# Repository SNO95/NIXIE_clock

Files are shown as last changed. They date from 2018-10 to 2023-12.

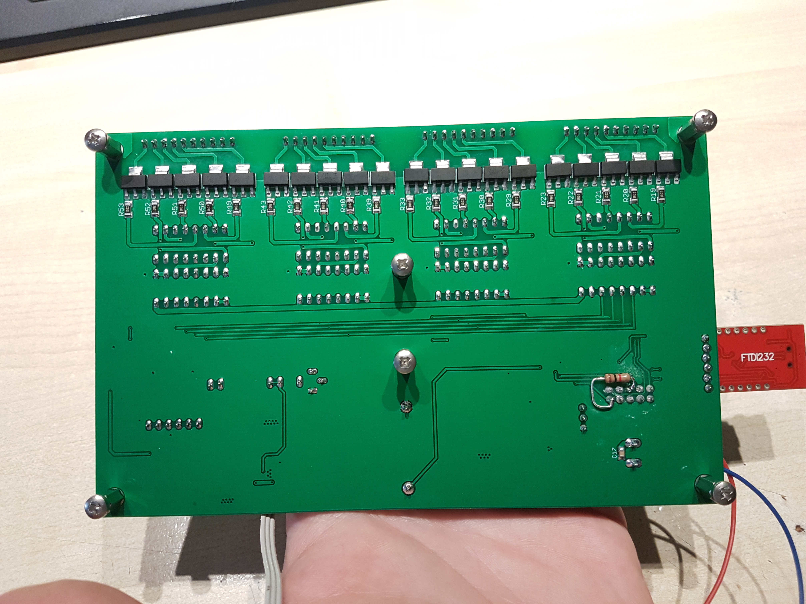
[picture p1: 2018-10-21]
20181021_120455.jpg

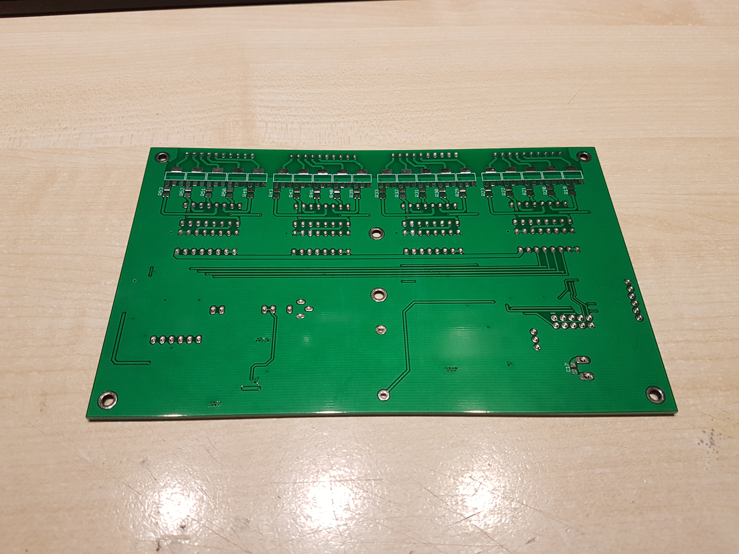
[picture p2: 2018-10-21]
20181021_120423.jpg

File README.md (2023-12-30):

# NIXIE_clock
ATmega328p and DS3231 based nixie clock.
PCBs are from JLC PCB, the first version had some errors (pictures are the first version, the battery hodlers silk screen was off by 0.5mm and the p channel mosfets in the h bridge were wired wrong, and I forgot the reset pullup on the ATmega) but I think they are fixed now. If you find anything please let me know.



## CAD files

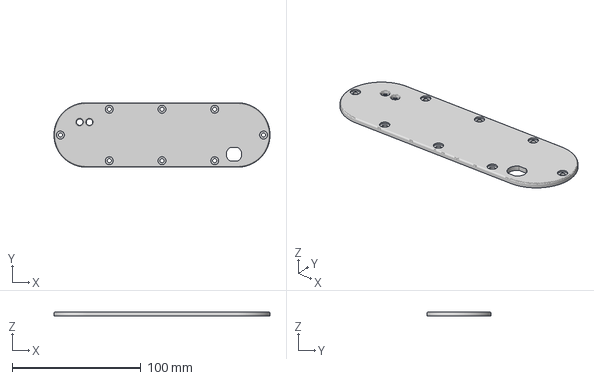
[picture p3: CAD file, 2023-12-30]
backplate.3mf
168.0 x 50.0 x 3.00 mm

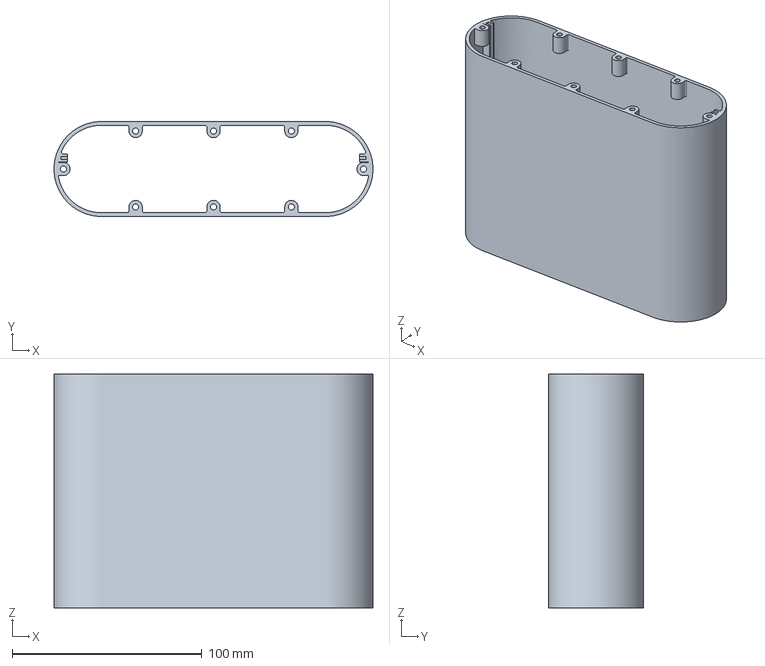
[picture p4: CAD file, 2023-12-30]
nixie body.3mf
168.0 x 50.0 x 123.0 mm

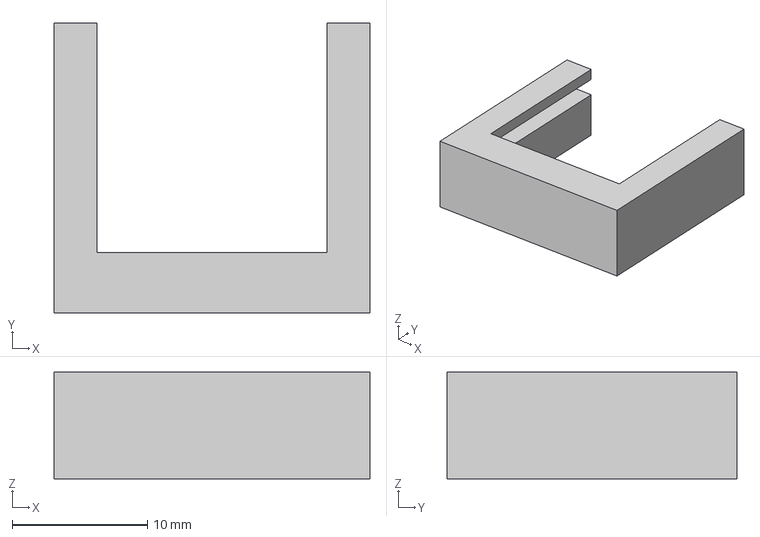
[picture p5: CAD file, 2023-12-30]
switch bracket.3mf
23.4 x 21.5 x 7.90 mm

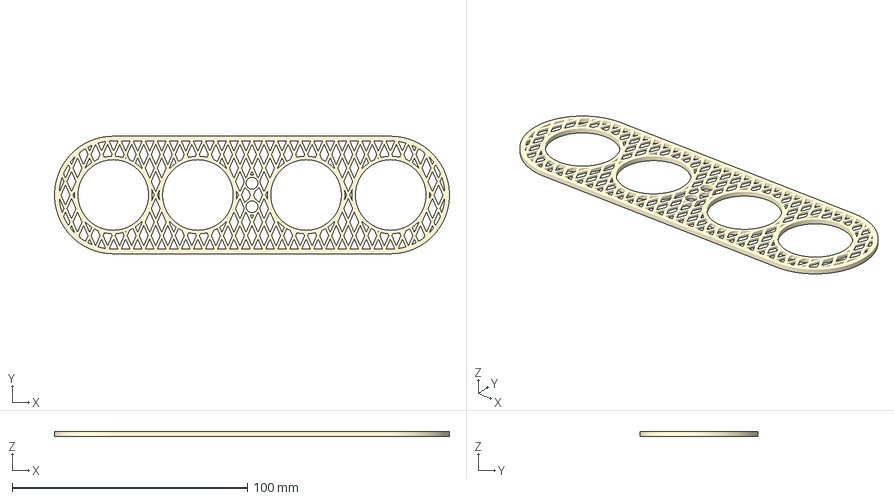
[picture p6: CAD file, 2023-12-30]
nixie grille.3mf
168.0 x 50.0 x 2.00 mm

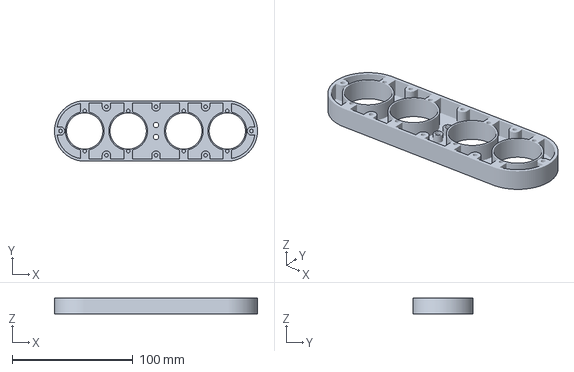
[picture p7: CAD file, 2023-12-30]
nixie panel.3mf
168.0 x 50.0 x 13.0 mm

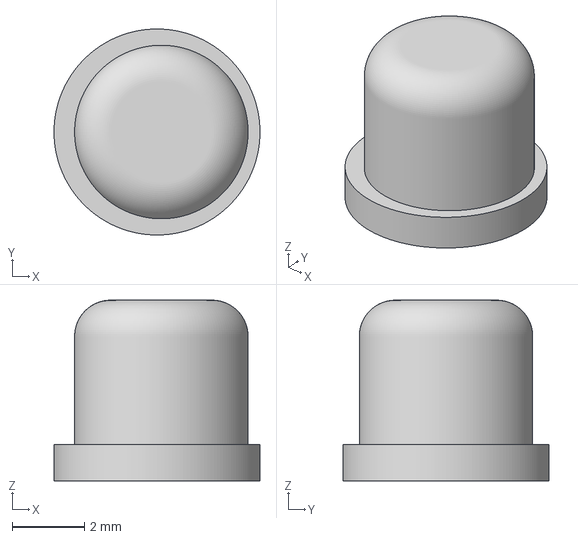
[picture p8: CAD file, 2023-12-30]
Button.3mf
5.70 x 5.70 x 5.00 mm

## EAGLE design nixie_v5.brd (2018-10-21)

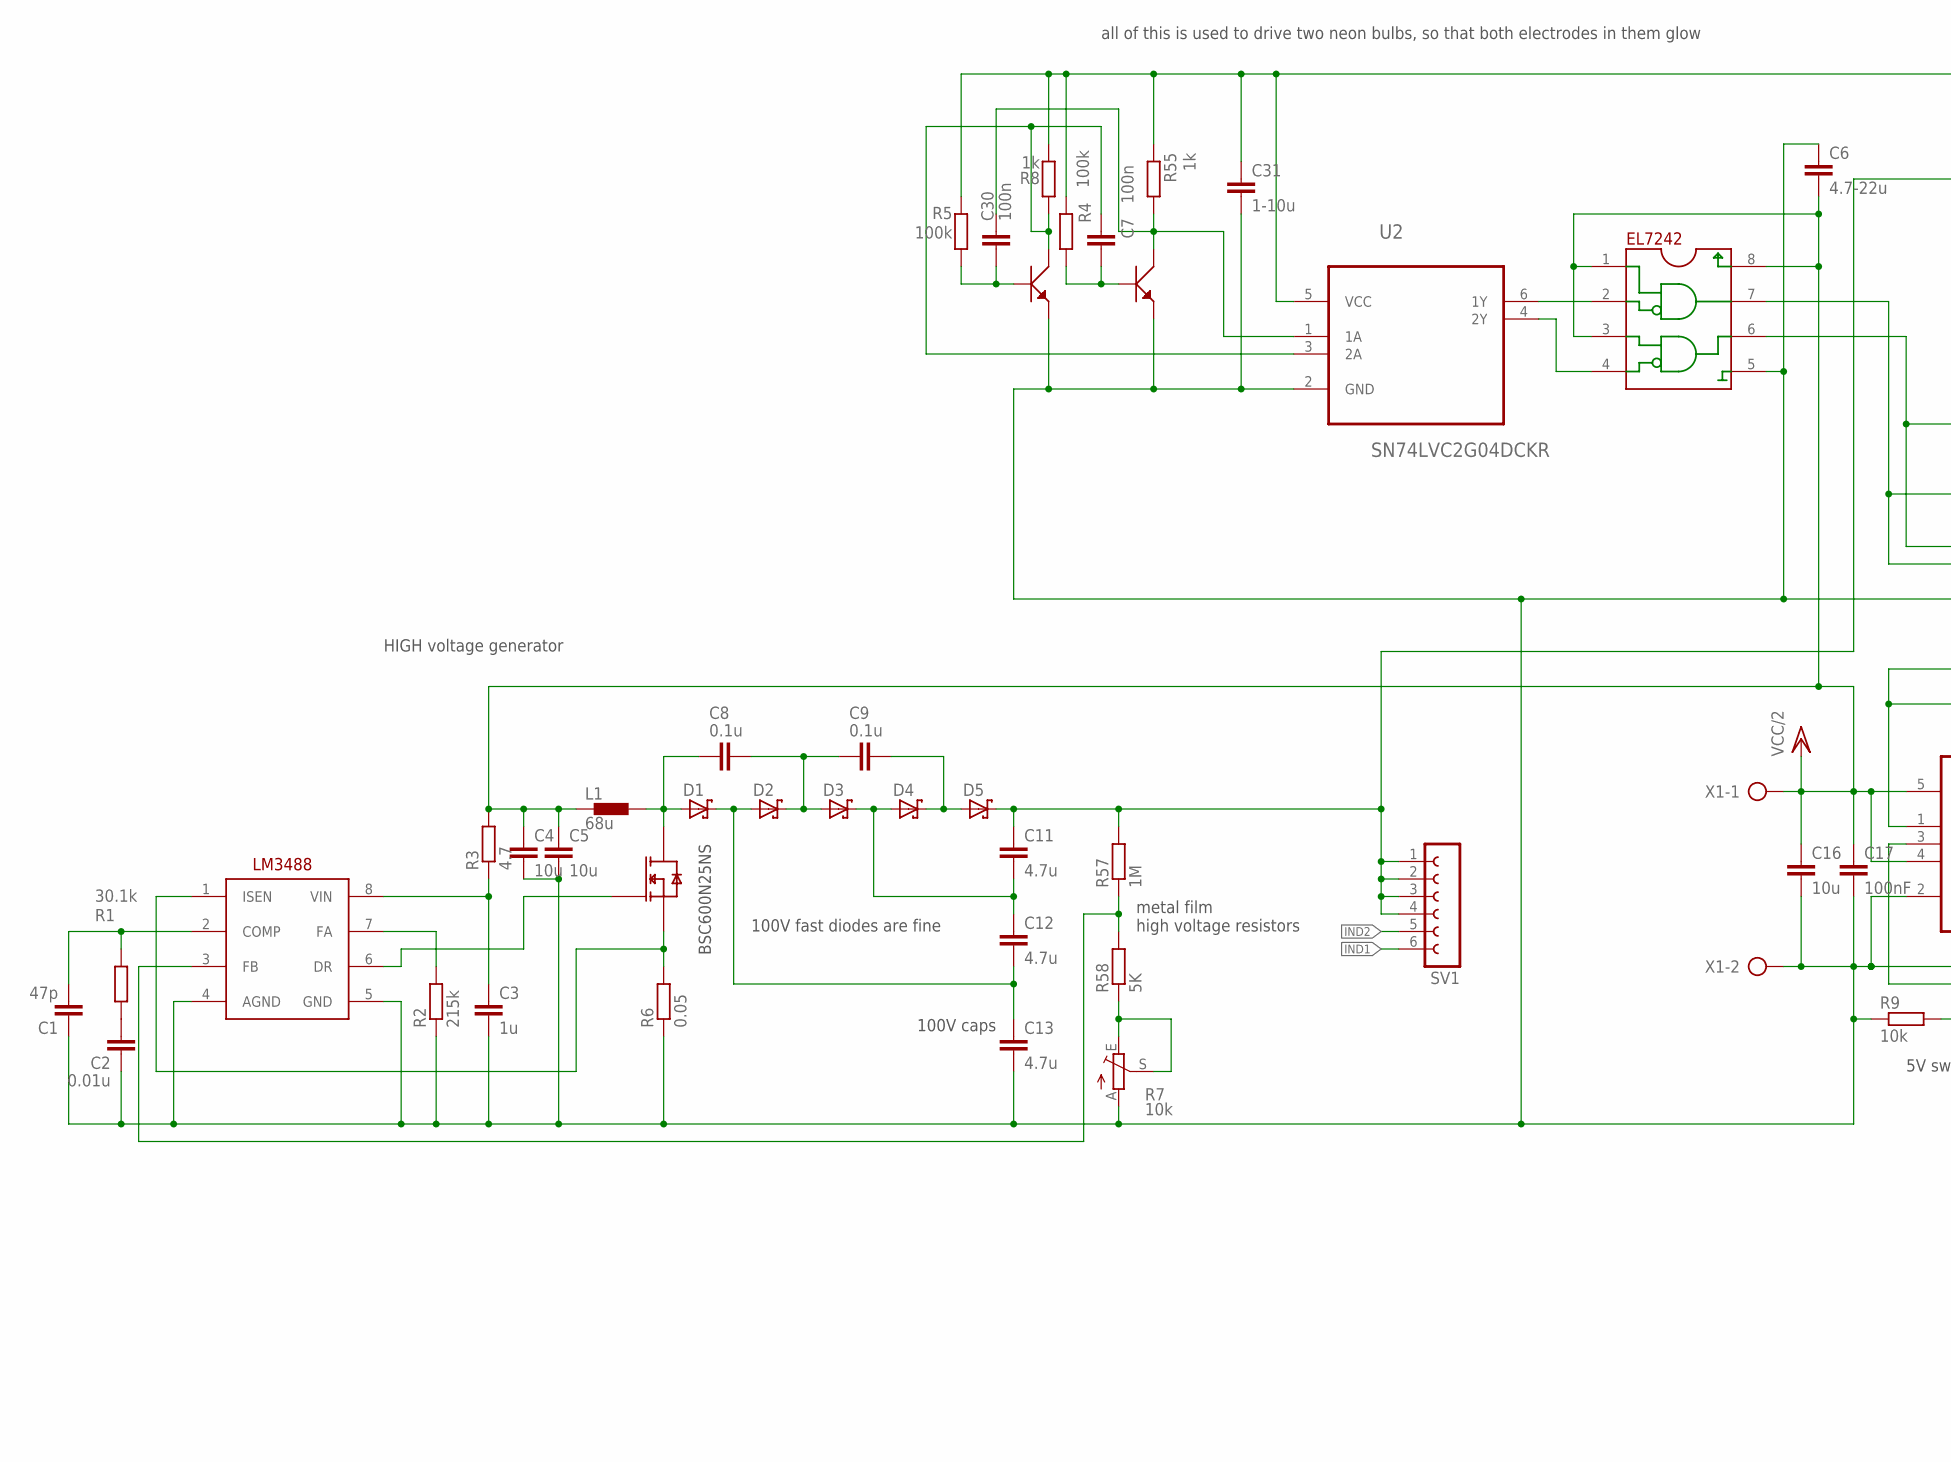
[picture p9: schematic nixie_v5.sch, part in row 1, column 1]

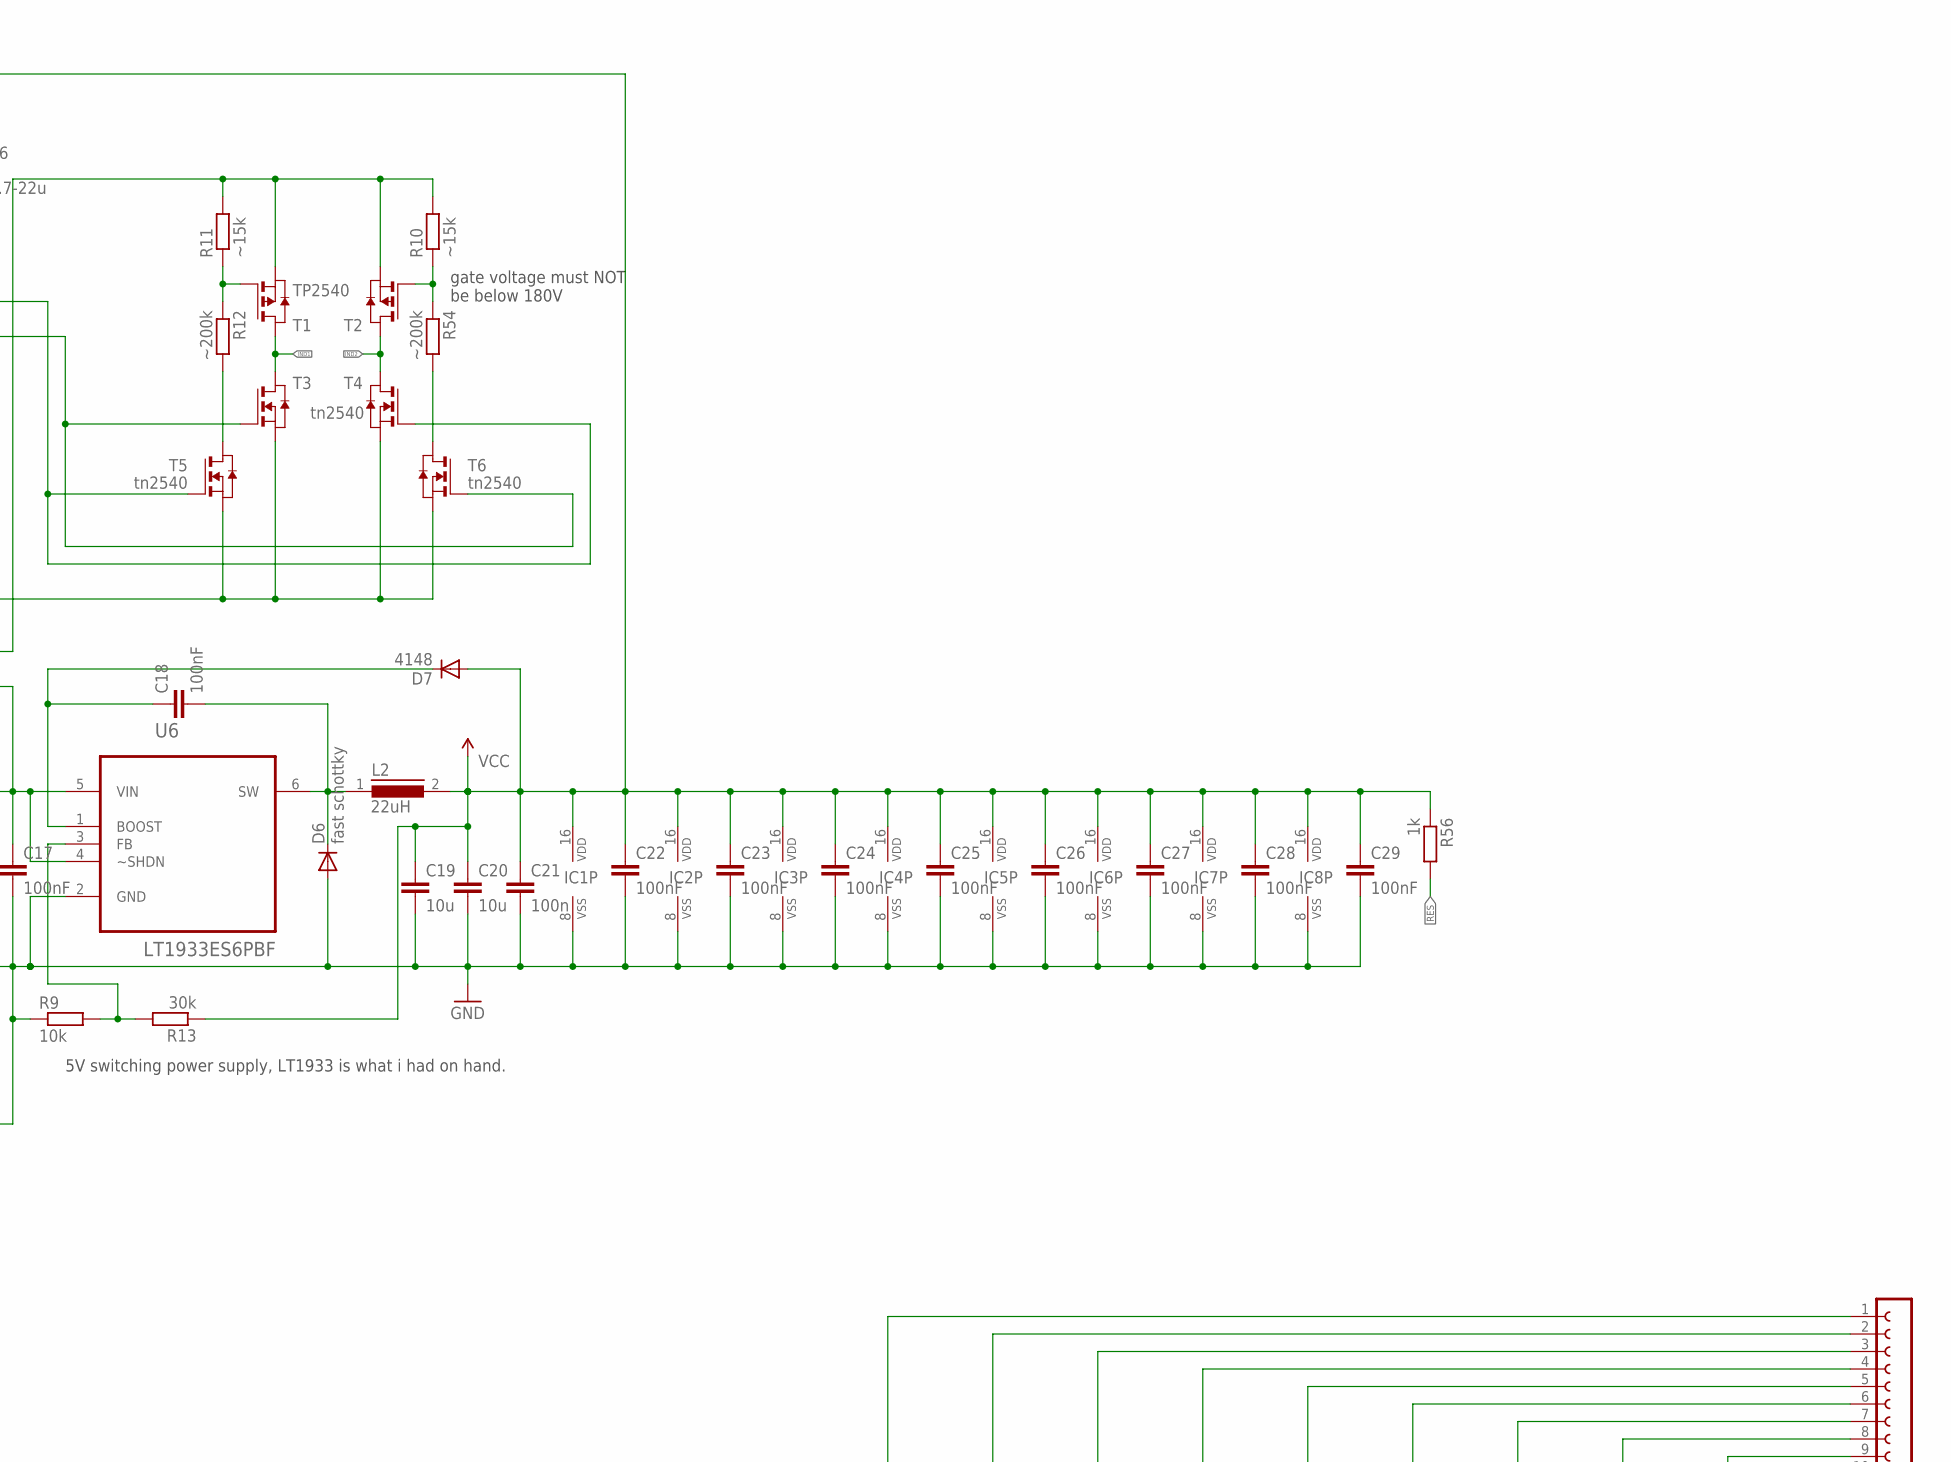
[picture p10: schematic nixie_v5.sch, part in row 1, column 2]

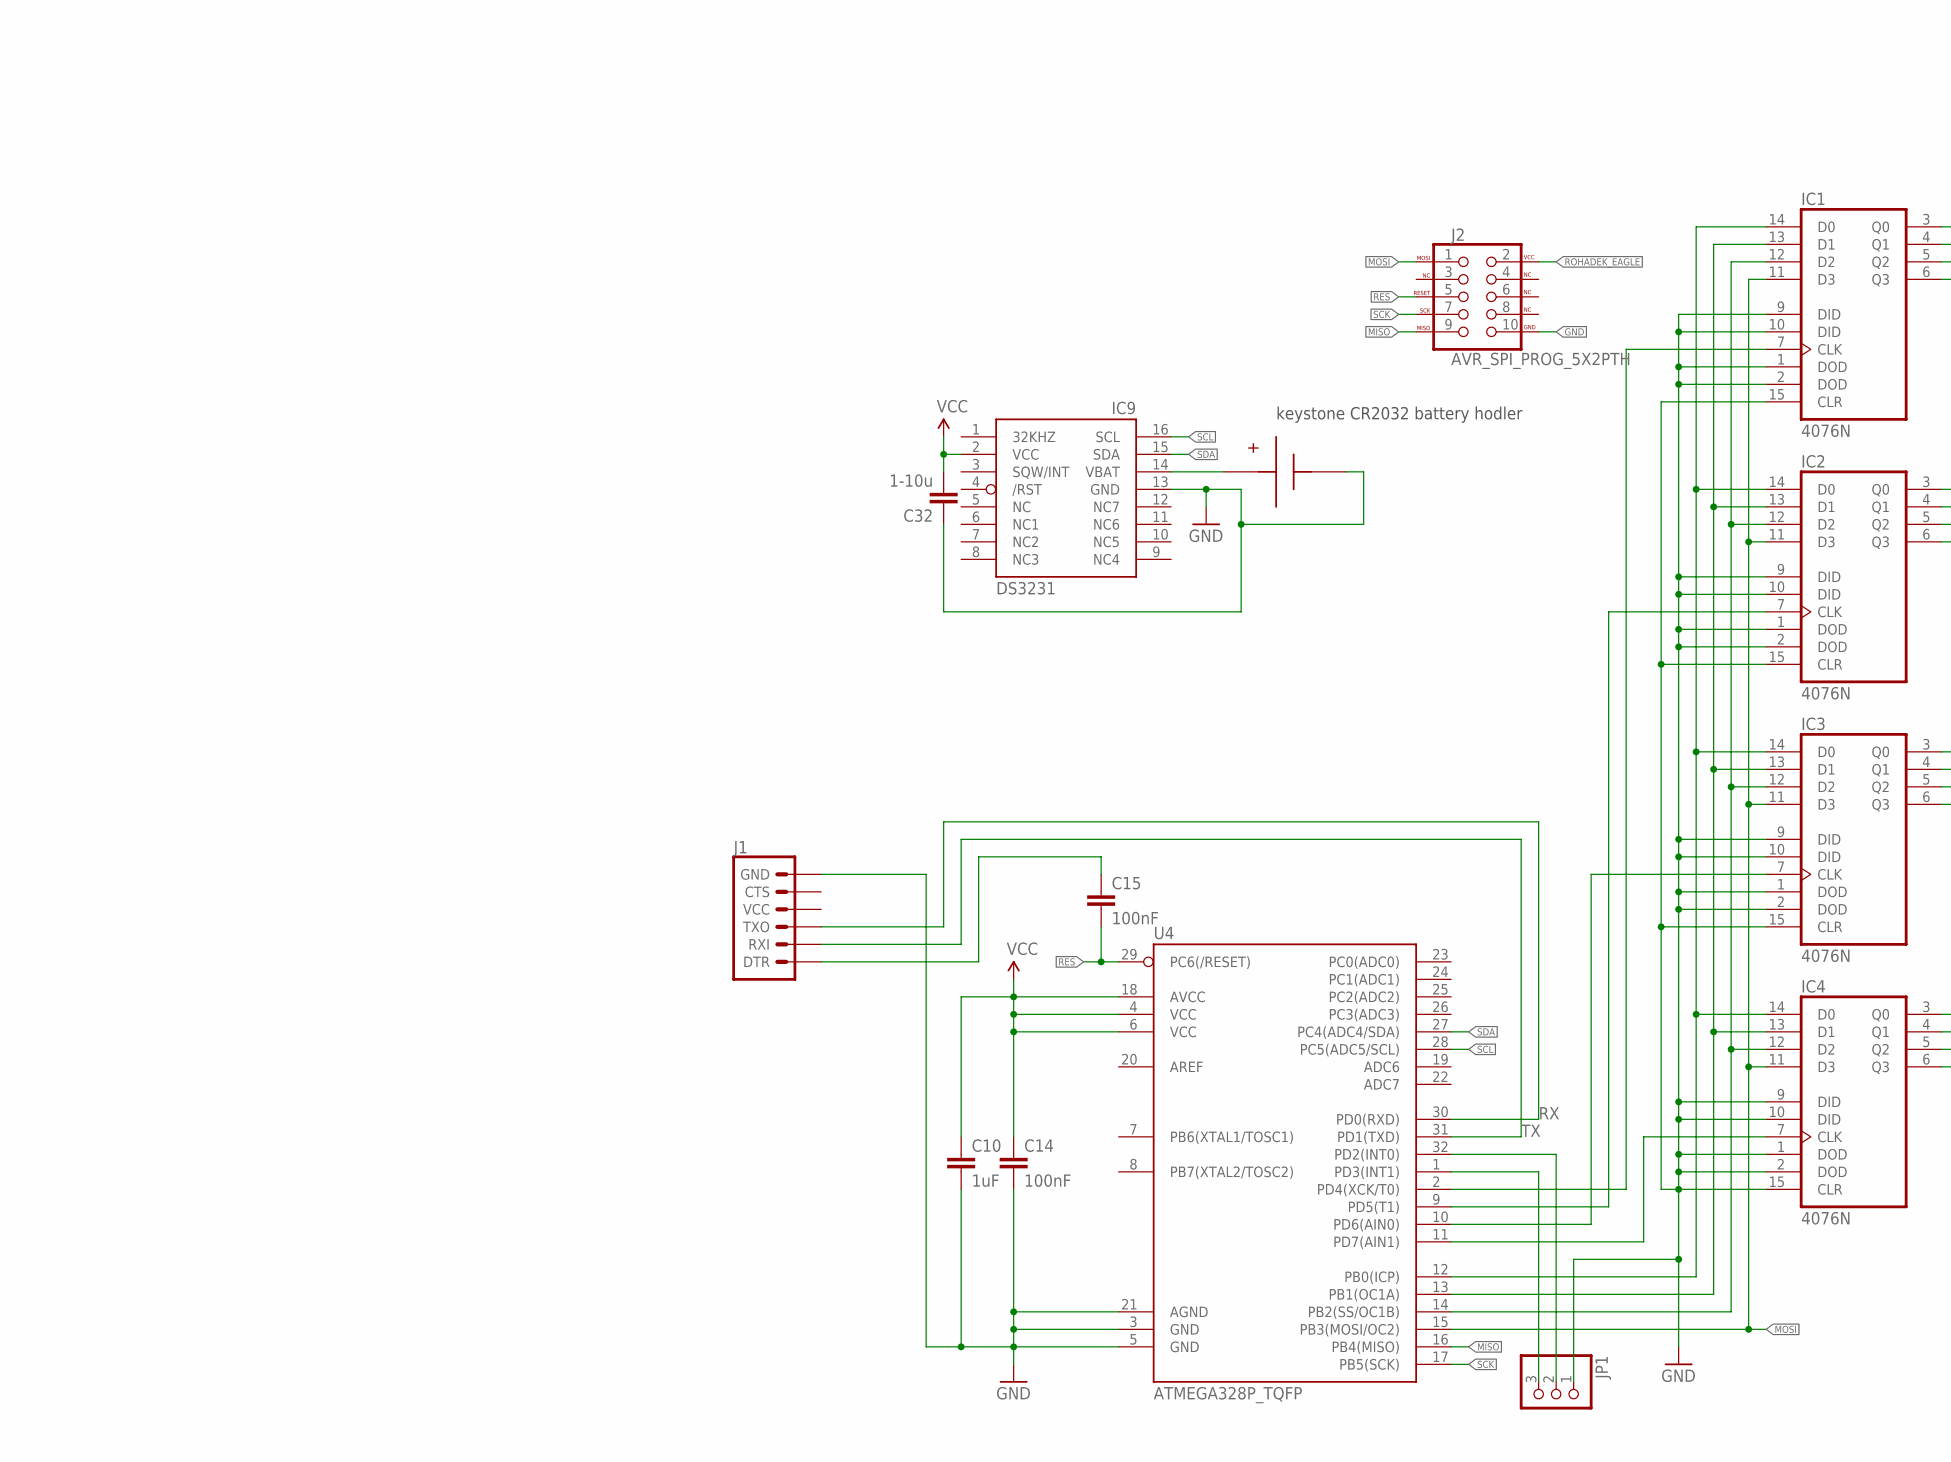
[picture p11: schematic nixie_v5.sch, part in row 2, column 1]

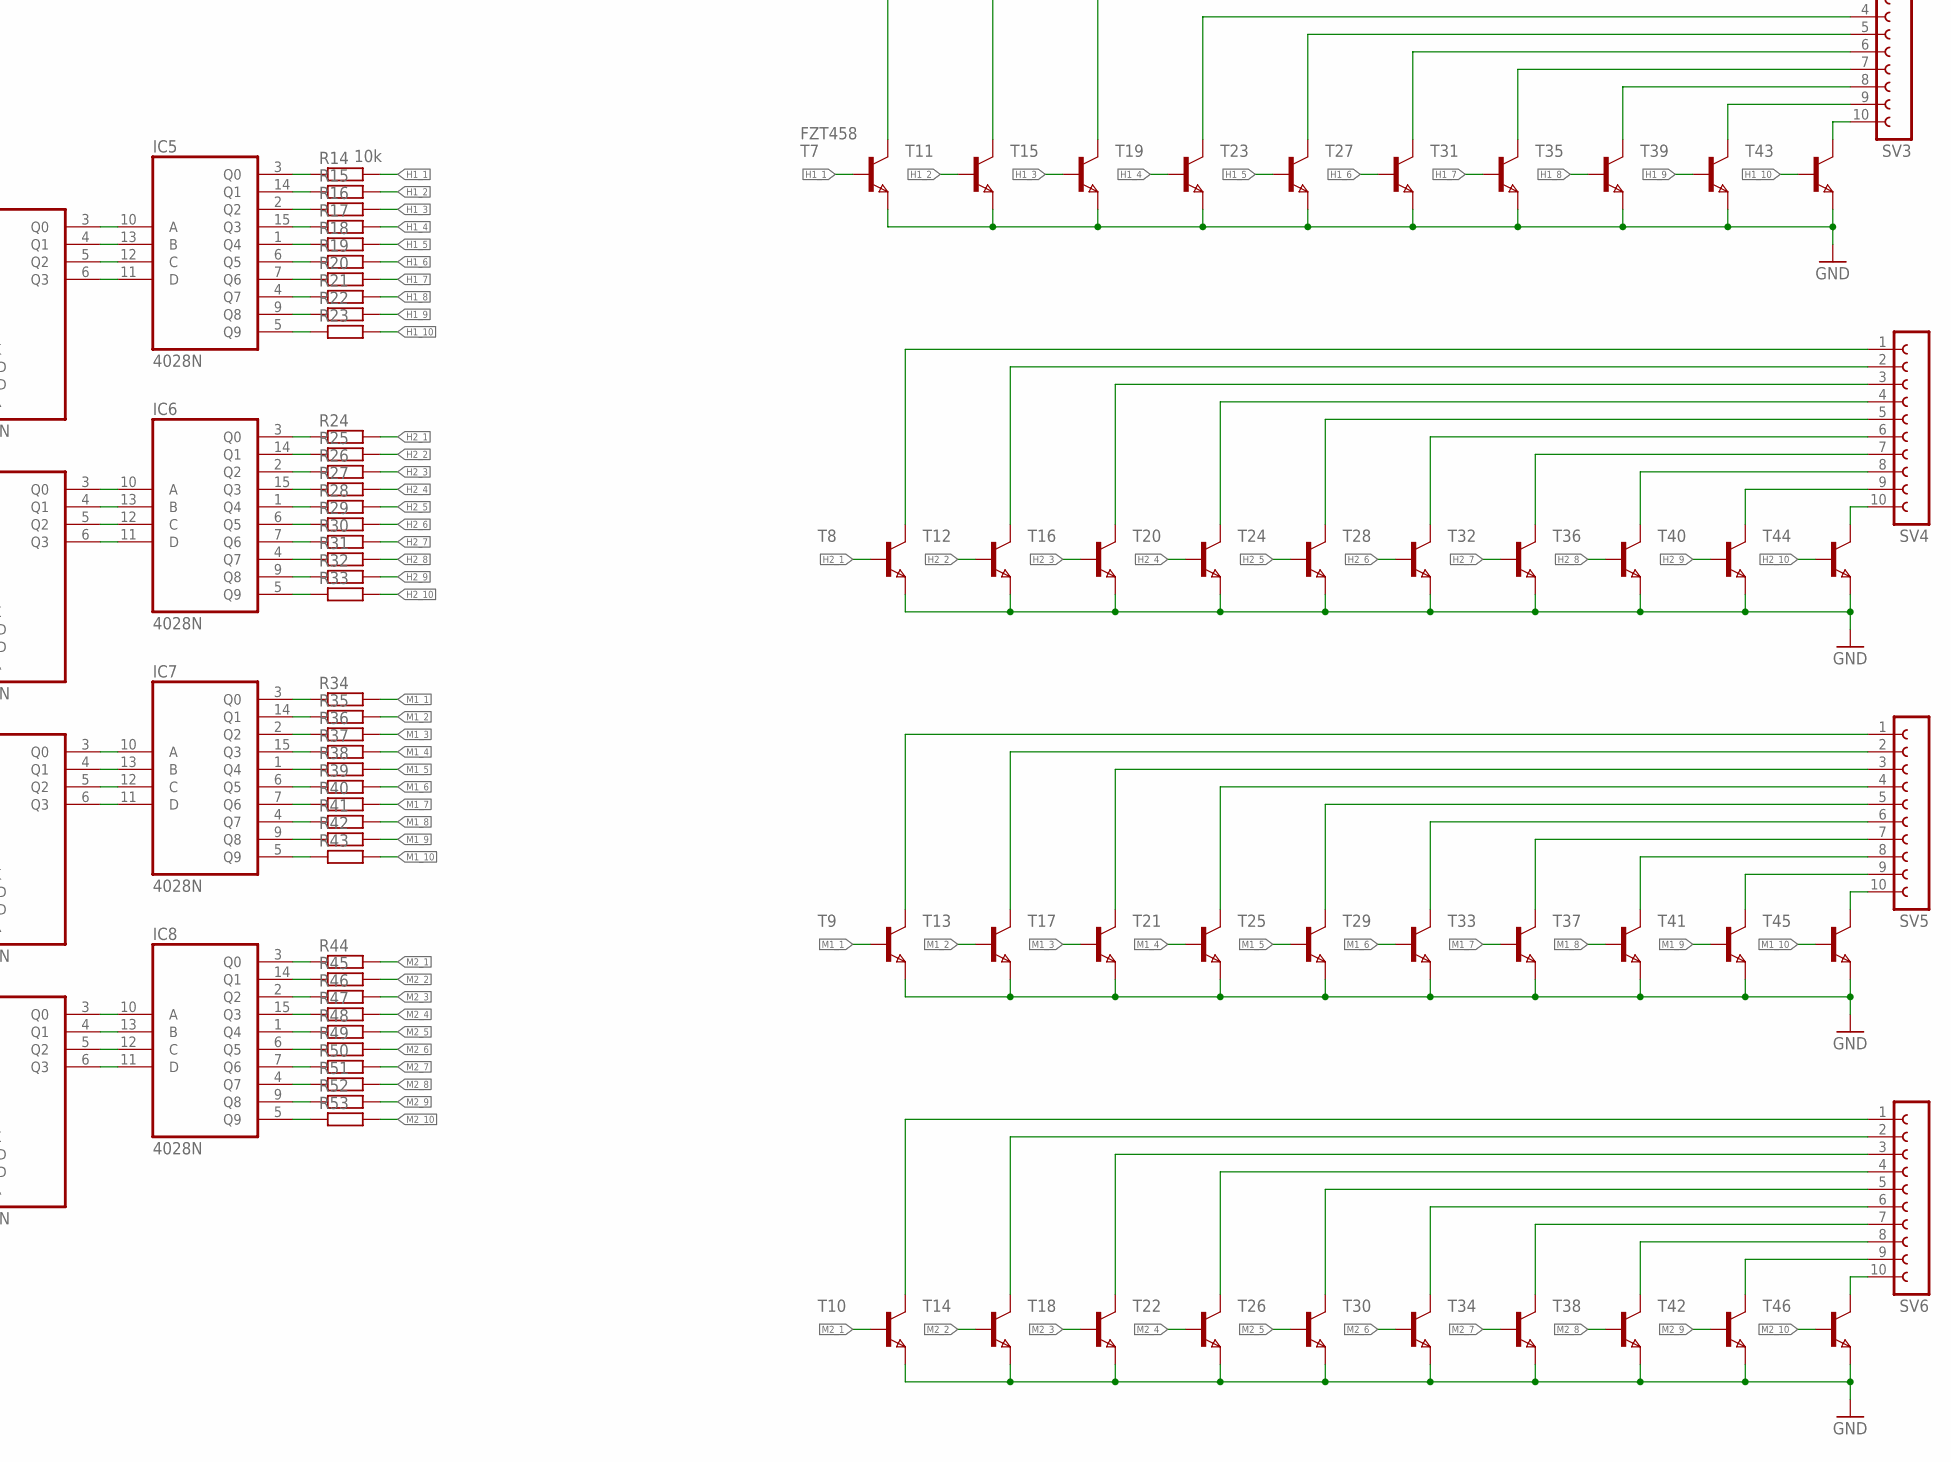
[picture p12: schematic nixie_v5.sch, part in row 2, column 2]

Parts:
BSC600N25NS: BSC600N25NS; PGTDSON
C1: 47p; C0402
C2: 0.01u; C0402
C3: 1u; C0805
C4, C5, C16, C19, C20: 10u; C1206
C6: 4.7-22u; C1206
C7, C30: 100n; C0402
C8, C9: 0.1u; C0805
C10: 1uF; C0402
C11, C12, C13: 4.7u; C2220K
C14, C15: 100nF; C0402
C17, C18: 100nF; C0805K
C21: 100n; C0805K
C22, C23, C24, C25, C26, C27, C28, C29: 100nF; C0805
C31, C32: 1-10u; C0805
D1, D2, D3, D4, D5: SCHOTTKY-DIODE; POWERDI123
D6: fast schottky; SOD123
D7: 4148; SOD123
EL7242: EL7242
IC1, IC2, IC3, IC4: 4076N; DIL16
IC5, IC6, IC7, IC8: 4028N; DIL16
IC9: DS3231/SO; SO16W
J1: 6_PIN_SERIAL_TARGETLOCK; 1X06_LOCK
J2: AVR_SPI_PROG_5X2PTH; 2X5
JP1: PINHD-1X3CB; 1X03-CLEANBIG
L1: 68u; DR1030
L2: 22uH; DR74
R1: 30.1k; R0402
R2: 215k; R0402
R3: 4.7; R0805
R4, R5: 100k; R0402
R6: 0.05; R2512
R7: 10k; S64Y
R8, R55, R56: 1k; R0402
R9: 10k; M0805
R10, R11: ~15k; M0805
R12, R54: ~200k; M0805
R13: 30k; M0805
R14: 10k; M1206
R15, R16, R17, R18, R19, R20, R21, R22, R23, R24, R25, R26, R27, R28, R29, R30, R31, R32, R33, R34, R35, R36, R37, R38, R39, R40, R41, R42, R43, R44, R45, R46, R47, R48, R49, R50, R51, R52, R53: R-EU_M1206; M1206
R57: 1M; R1206
R58: 5K; R1206
SV1: FE06-1; FE06
SV3, SV4, SV5, SV6: FE10-1; FE10
T1: TP2540; SOT89
T2: tp2540; SOT89
T3, T4, T5, T6: tn2540; SOT89
T7: FZT458; SOT223
T8, T9, T10, T11, T12, T13, T14, T15, T16, T17, T18, T19, T20, T21, T22, T23, T24, T25, T26, T27, T28, T29, T30, T31, T32, T33, T34, T35, T36, T37, T38, T39, T40, T41, T42, T43, T44, T45, T46: NPNSOT223; SOT223
U1: LM3488; VSSOP-8
U2: SN74LVC2G04DCKR; SOT65P210X110-6N
U4: ATMEGA328P_TQFP; TQFP32-08
U6: LT1933ES6PBF; SOT95P280X145-6N
U$1: RTC2032; CR2032
U$2: DUAL_NPNSC; SC-70
X1: AK300/2

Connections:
CLK_H1: IC1.7 (CLK), U4.2 (PD4(XCK/T0))
CLK_H2: IC2.7 (CLK), U4.9 (PD5(T1))
CLK_M1: IC3.7 (CLK), U4.10 (PD6(AIN0))
CLK_M2: IC4.7 (CLK), U4.11 (PD7(AIN1))
D0: IC1.14 (D0), IC2.14 (D0), IC3.14 (D0), IC4.14 (D0), U4.12 (PB0(ICP))
D1: IC1.13 (D1), IC2.13 (D1), IC3.13 (D1), IC4.13 (D1), U4.13 (PB1(OC1A))
D2: IC1.12 (D2), IC2.12 (D2), IC3.12 (D2), IC4.12 (D2), U4.14 (PB2(SS/OC1B))
GND: C1.1, C2.2, C3.2, C4.2, C5.2, C6.1, C10.2, C13.2, C14.2, C16.2, C17.2, C19.2, C20.2, C21.2, C22.2, C23.2, C24.2, C25.2, C26.2, C27.2, C28.2, C29.2, C31.2, C32.1, D6.A, EL7242.5, IC1.1 (DOD), IC1.2 (DOD), IC1.8 (VSS), IC1.9 (DID), IC1.10 (DID), IC1.15 (CLR), IC2.1 (DOD), IC2.2 (DOD), IC2.8 (VSS), IC2.9 (DID), IC2.10 (DID), IC2.15 (CLR), IC3.1 (DOD), IC3.2 (DOD), IC3.8 (VSS), IC3.9 (DID), IC3.10 (DID), IC3.15 (CLR), IC4.1 (DOD), IC4.2 (DOD), IC4.8 (VSS), IC4.9 (DID), IC4.10 (DID), IC4.15 (CLR), IC5.8 (VSS), IC6.8 (VSS), IC7.8 (VSS), IC8.8 (VSS), IC9.13 (GND), J1.6 (GND), J2.10 (GND), JP1.1, R2.1, R6.1, R7.A, R9.1, T3.3 (S), T4.3 (S), T5.3 (S), T6.3 (S), T7.3 (E), T8.3 (E), T9.3 (E), T10.3 (E), T11.3 (E), T12.3 (E), T13.3 (E), T14.3 (E), T15.3 (E), T16.3 (E), T17.3 (E), T18.3 (E), T19.3 (E), T20.3 (E), T21.3 (E), T22.3 (E), T23.3 (E), T24.3 (E), T25.3 (E), T26.3 (E), T27.3 (E), T28.3 (E), T29.3 (E), T30.3 (E), T31.3 (E), T32.3 (E), T33.3 (E), T34.3 (E), T35.3 (E), T36.3 (E), T37.3 (E), T38.3 (E), T39.3 (E), T40.3 (E), T41.3 (E), T42.3 (E), T43.3 (E), T44.3 (E), T45.3 (E), T46.3 (E), U1.4 (AGND), U1.5 (GND), U2.2 (GND), U4.3 (GND), U4.5 (GND), U4.21 (AGND), U6.2 (GND), U$1.- (BATT-), U$2.1 (EMITTER), U$2.4 (EMITTER1), X1.2
H1_1: R14.2, T7.1 (B)
H1_2: R15.2, T11.1 (B)
H1_3: R16.2, T15.1 (B)
H1_4: R17.2, T19.1 (B)
H1_5: R18.2, T23.1 (B)
H1_6: R19.2, T27.1 (B)
H1_7: R20.2, T31.1 (B)
H1_8: R21.2, T35.1 (B)
H1_9: R22.2, T39.1 (B)
H1_10: R23.2, T43.1 (B)
H2_1: R24.2, T8.1 (B)
H2_2: R25.2, T12.1 (B)
H2_3: R26.2, T16.1 (B)
H2_4: R27.2, T20.1 (B)
H2_5: R28.2, T24.1 (B)
H2_6: R29.2, T28.1 (B)
H2_7: R30.2, T32.1 (B)
H2_8: R31.2, T36.1 (B)
H2_9: R32.2, T40.1 (B)
H2_10: R33.2, T44.1 (B)
INC: JP1.3, U4.1 (PD3(INT1))
IND1: SV1.6, T1.2 (D), T3.2 (D), T3.2@1 (D)
IND2: SV1.5, T2.2 (D), T4.2 (D), T4.2@1 (D)
M1_1: R34.2, T9.1 (B)
M1_2: R35.2, T13.1 (B)
M1_3: R36.2, T17.1 (B)
M1_4: R37.2, T21.1 (B)
M1_5: R38.2, T25.1 (B)
M1_6: R39.2, T29.1 (B)
M1_7: R40.2, T33.1 (B)
M1_8: R41.2, T37.1 (B)
M1_9: R42.2, T41.1 (B)
M1_10: R43.2, T45.1 (B)
M2_1: R44.2, T10.1 (B)
M2_2: R45.2, T14.1 (B)
M2_3: R46.2, T18.1 (B)
M2_4: R47.2, T22.1 (B)
M2_5: R48.2, T26.1 (B)
M2_6: R49.2, T30.1 (B)
M2_7: R50.2, T34.1 (B)
M2_8: R51.2, T38.1 (B)
M2_9: R52.2, T42.1 (B)
M2_10: R53.2, T46.1 (B)
MISO: J2.9 (MISO), U4.16 (PB4(MISO))
MOSI: IC1.11 (D3), IC2.11 (D3), IC3.11 (D3), IC4.11 (D3), J2.1 (MOSI), U4.15 (PB3(MOSI/OC2))
unnamed: IC9.14 (VBAT), U$1.+ (BATT+)
unnamed: R11.1, R12.1, T1.1 (G)
unnamed: R7.E, R7.S, R58.1
unnamed: IC1.3 (Q0), IC5.10 (A)
unnamed: IC1.6 (Q3), IC5.11 (D)
unnamed: IC1.5 (Q2), IC5.12 (C)
unnamed: IC1.4 (Q1), IC5.13 (B)
unnamed: IC2.3 (Q0), IC6.10 (A)
unnamed: IC2.6 (Q3), IC6.11 (D)
unnamed: IC2.5 (Q2), IC6.12 (C)
unnamed: IC2.4 (Q1), IC6.13 (B)
unnamed: IC3.3 (Q0), IC7.10 (A)
unnamed: IC3.6 (Q3), IC7.11 (D)
unnamed: IC3.5 (Q2), IC7.12 (C)
unnamed: IC3.4 (Q1), IC7.13 (B)
unnamed: IC4.3 (Q0), IC8.10 (A)
unnamed: IC4.6 (Q3), IC8.11 (D)
unnamed: IC4.5 (Q2), IC8.12 (C)
unnamed: IC4.4 (Q1), IC8.13 (B)
unnamed: SV3.1, T7.2 (C), T7.4 (C)
unnamed: SV3.2, T11.2 (C), T11.4 (C)
unnamed: C18.1, D7.C, U6.1 (BOOST)
unnamed: SV3.3, T15.2 (C), T15.4 (C)
unnamed: SV3.4, T19.2 (C), T19.4 (C)
unnamed: SV3.5, T23.2 (C), T23.4 (C)
unnamed: SV3.6, T27.2 (C), T27.4 (C)
unnamed: SV3.7, T31.2 (C), T31.4 (C)
unnamed: SV3.8, T35.2 (C), T35.4 (C)
unnamed: SV3.9, T39.2 (C), T39.4 (C)
unnamed: SV3.10, T43.2 (C), T43.4 (C)
unnamed: C3.1, R3.1, U1.8 (VIN)
unnamed: IC5.3 (Q0), R14.1
unnamed: IC5.14 (Q1), R15.1
unnamed: IC5.2 (Q2), R16.1
unnamed: IC5.15 (Q3), R17.1
unnamed: IC5.1 (Q4), R18.1
unnamed: IC5.6 (Q5), R19.1
unnamed: IC5.7 (Q6), R20.1
unnamed: IC5.4 (Q7), R21.1
unnamed: IC5.9 (Q8), R22.1
unnamed: IC5.5 (Q9), R23.1
unnamed: IC6.3 (Q0), R24.1
unnamed: IC6.14 (Q1), R25.1
unnamed: IC6.2 (Q2), R26.1
unnamed: IC6.15 (Q3), R27.1
unnamed: IC6.1 (Q4), R28.1
unnamed: IC6.6 (Q5), R29.1
unnamed: IC6.7 (Q6), R30.1
unnamed: IC6.4 (Q7), R31.1
unnamed: IC6.9 (Q8), R32.1
unnamed: IC6.5 (Q9), R33.1
unnamed: SV4.1, T8.2 (C), T8.4 (C)
unnamed: SV4.2, T12.2 (C), T12.4 (C)
unnamed: SV4.3, T16.2 (C), T16.4 (C)
unnamed: SV4.4, T20.2 (C), T20.4 (C)
unnamed: SV4.5, T24.2 (C), T24.4 (C)
unnamed: SV4.6, T28.2 (C), T28.4 (C)
unnamed: SV4.7, T32.2 (C), T32.4 (C)
unnamed: SV4.8, T36.2 (C), T36.4 (C)
unnamed: SV4.9, T40.2 (C), T40.4 (C)
unnamed: SV4.10, T44.2 (C), T44.4 (C)
unnamed: IC8.3 (Q0), R44.1
unnamed: IC8.14 (Q1), R45.1
unnamed: IC8.2 (Q2), R46.1
unnamed: IC8.15 (Q3), R47.1
unnamed: IC8.1 (Q4), R48.1
unnamed: IC8.6 (Q5), R49.1
unnamed: IC8.7 (Q6), R50.1
unnamed: IC8.4 (Q7), R51.1
unnamed: IC8.9 (Q8), R52.1
unnamed: IC8.5 (Q9), R53.1
unnamed: IC7.3 (Q0), R34.1
unnamed: IC7.14 (Q1), R35.1
unnamed: IC7.2 (Q2), R36.1
unnamed: IC7.15 (Q3), R37.1
unnamed: IC7.1 (Q4), R38.1
unnamed: IC7.6 (Q5), R39.1
unnamed: IC7.7 (Q6), R40.1
unnamed: IC7.4 (Q7), R41.1
unnamed: IC7.9 (Q8), R42.1
unnamed: IC7.5 (Q9), R43.1
unnamed: R9.2, R13.2, U6.3 (FB)
unnamed: BSC600N25NS.DRAIN, C8.2, D1.A, L1.2
unnamed: R2.2, U1.7 (FA)
unnamed: BSC600N25NS.GATE, U1.6 (DR)
unnamed: BSC600N25NS.SOURCE, BSC600N25NS.SOURCE1 (SOURCE), BSC600N25NS.SOURCE3 (SOURCE), R6.2, U1.1 (ISEN)
unnamed: C8.1, C9.2, D2.K (C), D3.A
unnamed: C9.1, D4.K (C), D5.A
unnamed: C12.2, C13.1, D1.K (C), D2.A
unnamed: SV5.1, T9.2 (C), T9.4 (C)
unnamed: SV5.2, T13.2 (C), T13.4 (C)
unnamed: SV5.3, T17.2 (C), T17.4 (C)
unnamed: SV5.4, T21.2 (C), T21.4 (C)
unnamed: SV5.5, T25.2 (C), T25.4 (C)
unnamed: SV5.6, T29.2 (C), T29.4 (C)
unnamed: SV5.7, T33.2 (C), T33.4 (C)
unnamed: SV5.8, T37.2 (C), T37.4 (C)
unnamed: SV5.9, T41.2 (C), T41.4 (C)
unnamed: SV5.10, T45.2 (C), T45.4 (C)
unnamed: SV6.1, T10.2 (C), T10.4 (C)
unnamed: SV6.2, T14.2 (C), T14.4 (C)
unnamed: SV6.3, T18.2 (C), T18.4 (C)
unnamed: SV6.4, T22.2 (C), T22.4 (C)
unnamed: SV6.5, T26.2 (C), T26.4 (C)
unnamed: SV6.6, T30.2 (C), T30.4 (C)
unnamed: SV6.7, T34.2 (C), T34.4 (C)
unnamed: SV6.8, T38.2 (C), T38.4 (C)
unnamed: SV6.9, T42.2 (C), T42.4 (C)
unnamed: SV6.10, T46.2 (C), T46.4 (C)
unnamed: C11.2, C12.1, D3.K (C), D4.A
unnamed: C1.2, R1.2, U1.2 (COMP)
unnamed: R57.1, R58.2, U1.3 (FB)
unnamed: C2.1, R1.1
unnamed: C15.1, J1.1 (DTR)
unnamed: R10.1, R54.1, T2.1 (G)
unnamed: EL7242.6, T3.1 (G), T6.1 (G)
unnamed: C30.2, R5.2, U$2.2 (BASE)
unnamed: C7.2, R4.2, U$2.5 (BASE1)
unnamed: C7.1, R8.2, U2.3 (2A), U$2.6 (COLLECTOR)
unnamed: R12.2, T5.2 (D), T5.2@1 (D)
unnamed: R54.2, T6.2 (D), T6.2@1 (D)
unnamed: C30.1, R55.2, U2.1 (1A), U$2.3 (COLLECTOR1)
unnamed: EL7242.7, T4.1 (G), T5.1 (G)
unnamed: C11.1, D5.K (C), R10.2, R11.2, R57.2, SV1.1, SV1.2, SV1.3, SV1.4, T1.3 (S), T2.3 (S)
unnamed: EL7242.2, U2.6 (1Y)
unnamed: EL7242.4, U2.4 (2Y)
NC: J2.4 (NC), J2.6 (NC), J2.8 (NC)
RES: C15.2, J2.5 (RESET), R56.2, U4.29 (PC6(/RESET))
ROHADEK_EAGLE: J2.2 (VCC)
RX: J1.3 (TXO), U4.30 (PD0(RXD))
SCK: J2.7 (SCK), U4.17 (PB5(SCK))
SCL: IC9.16 (SCL), U4.28 (PC5(ADC5/SCL))
SDA: IC9.15 (SDA), U4.27 (PC4(ADC4/SDA))
SET: JP1.2, U4.32 (PD2(INT0))
SW: C18.2, D6.C, L2.1, U6.6 (SW)
TX: J1.2 (RXI), U4.31 (PD1(TXD))
VCC: C10.1, C14.1, C19.1, C20.1, C21.1, C22.1, C23.1, C24.1, C25.1, C26.1, C27.1, C28.1, C29.1, C31.1, C32.2, D7.A, IC1.16 (VDD), IC2.16 (VDD), IC3.16 (VDD), IC4.16 (VDD), IC5.16 (VDD), IC6.16 (VDD), IC7.16 (VDD), IC8.16 (VDD), IC9.2 (VCC), L2.2, R4.1, R5.1, R8.1, R13.1, R55.1, R56.1, U2.5 (VCC), U4.4 (VCC), U4.6 (VCC), U4.18 (AVCC)
VCC/2: C4.1, C5.1, C6.2, C16.1, C17.1, EL7242.1, EL7242.3, EL7242.8, L1.1, R3.2, U6.4 (~SHDN), U6.5 (VIN), X1.1

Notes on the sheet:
gate voltage must NOT be below 180V
all of this is used to drive two neon bulbs, so that both electrodes in them glow
5V switching power supply, LT1933 is what i had on hand.
HIGH voltage generator
metal film high voltage resistors
BSC600N25NS
100V fast diodes are fine
100V caps
keystone CR2032 battery hodler

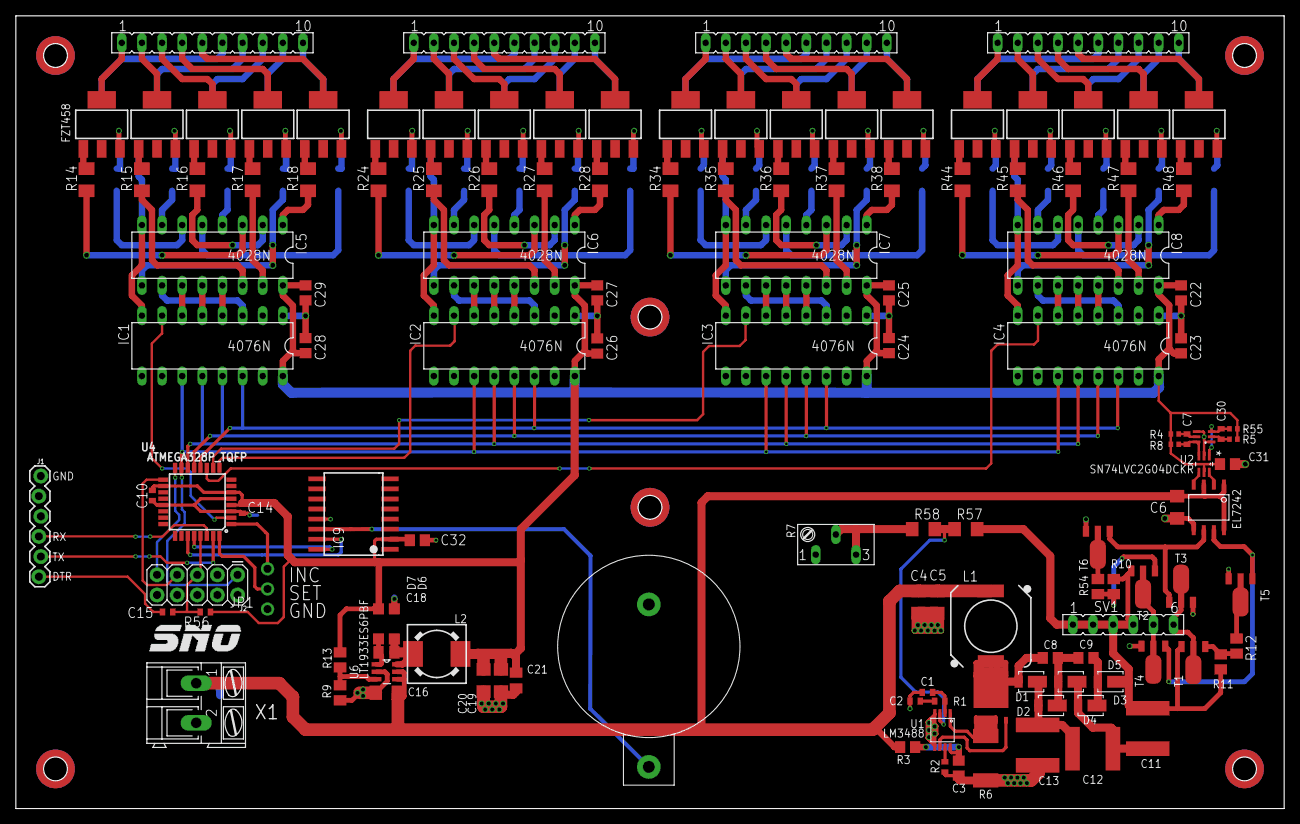
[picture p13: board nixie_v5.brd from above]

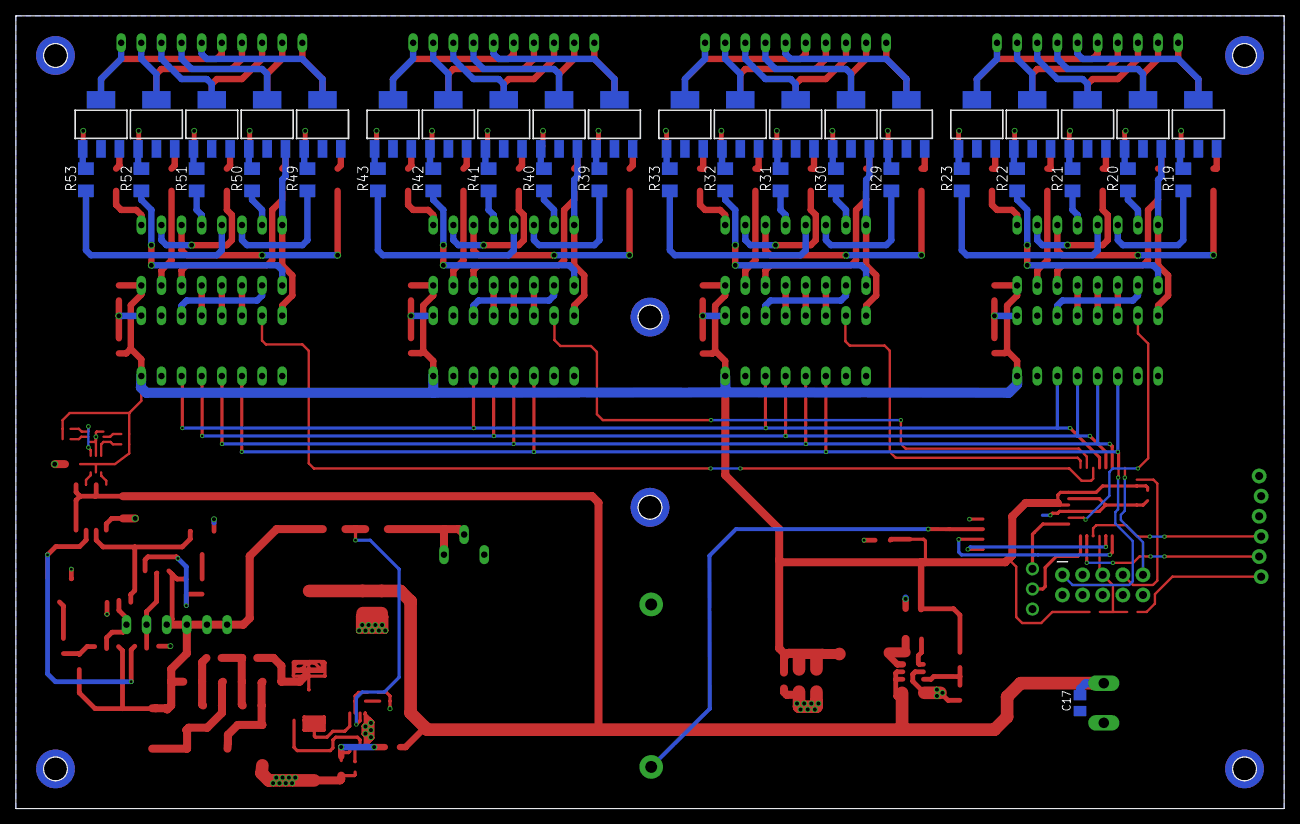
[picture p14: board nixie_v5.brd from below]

Board: 2 copper layers, 160.0 x 100.0 mm, 171 parts (41 on the bottom side), 190 nets.

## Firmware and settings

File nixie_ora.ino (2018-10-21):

#include "Wire.h"

byte decToBcd(byte val)                                           //value converter
{
  return( (val/10*16) + (val%10) );
}
byte bcdToDec(byte val)
{
  return( (val/16*10) + (val%16) );
}

byte minutes      = 0;                                            //holds the minutes read from the DS3231
byte hours        = 0;                                            //holds the hours read from the DS3231
byte counter      = 0;                                            //used for incrementing the values mentioned above
bool flag         = 0;                                            //used for navigating betveen menus

void setup() {
  DDRB = 0xFF;                                                    //The DDRB registers first four outputs are wired to the D registers inputs
  pinMode(2,INPUT_PULLUP);                                        //set
  pinMode(3,INPUT_PULLUP);                                        //increase
  pinMode(4,OUTPUT);                                              //minutes_lower_clk
  pinMode(5,OUTPUT);                                              //minutes_upper_clk
  pinMode(6,OUTPUT);                                              //hours_lower_clk
  pinMode(7,OUTPUT);                                              //hours_upper_clk
  digitalWrite(4,LOW);
  digitalWrite(5,LOW);
  digitalWrite(6,LOW);
  digitalWrite(7,LOW);
  Wire.begin();
  Serial.begin(9600);
  }

void loop() {
  
  Wire.beginTransmission(0x68);                                   //read the time from the DS3231
  Wire.write(1);
  Wire.endTransmission();
  Wire.requestFrom(0x68,1);
  minutes = Wire.read();
  
  Wire.beginTransmission(0x68);
  Wire.write(2);
  Wire.endTransmission();
  Wire.requestFrom(0x68,1);
  hours = (Wire.read() & 0x3f);

  Serial.print(bcdToDec(hours));
  Serial.print(":");
  Serial.println(bcdToDec(minutes));
  
  PORTB = hours;                                                  //second half of the hours
  delay(5);
  digitalWrite(6,HIGH);
  delay(5);
  digitalWrite(6,LOW);
  
  PORTB = hours>>4;                                               //shift by four the get the first half of the hours to the D registers 
  delay(5);
  digitalWrite(7,HIGH);
  delay(5);
  digitalWrite(7,LOW);
  
  PORTB = minutes;                                                //second half of the minutes
  delay(5);
  digitalWrite(4,HIGH);
  delay(5);
  digitalWrite(4,LOW);
  
  PORTB = minutes>>4;                                             //shift by four the get the first half of the minutes to the D registers
  delay(5);
  digitalWrite(5,HIGH);
  delay(5);
  digitalWrite(5,LOW);
  
  if(digitalRead(2)==LOW){                                        //if set is low enter the time setting menu
    Serial.println("set");
    do{
      PORTB=0xFF;                                                 //turn "off" the displays, the CD4028 will not turn on any of its outputs if the input value is above 9 or 1001.
      delay(5);
      digitalWrite(4,HIGH);
      digitalWrite(5,HIGH);
      digitalWrite(6,HIGH);
      digitalWrite(7,HIGH);
      delay(5);
      digitalWrite(4,LOW);
      digitalWrite(5,LOW);
      digitalWrite(6,LOW);
      digitalWrite(7,LOW);
      delay(50);                                                  //de-bounce
      while(digitalRead(2)==HIGH){                                //if set is released enter the hour incrementing part of the code
        flag=1;
         Serial.print("hours");
         Serial.print(": ");
         Serial.println(bcdToDec(hours));
         PORTB = hours;
         delay(5);
         digitalWrite(6,HIGH);
         delay(5);
         digitalWrite(6,LOW);
  
         PORTB = hours>>4;
         delay(5);
         digitalWrite(7,HIGH);
         delay(5);
          digitalWrite(7,LOW);
          if(digitalRead(3)==LOW){                                //hours and minutes are stored in BCD form, for me it was easier to increment the values this way.
            counter = bcdToDec(hours);
            counter++;
            hours = decToBcd(counter);
              if((bcdToDec(hours))==24){
                hours=0;
              }
            delay(200);
              PORTB = hours;
              delay(5);
              digitalWrite(6,HIGH);
              delay(5);
              digitalWrite(6,LOW);
  
              PORTB = hours>>4;
              delay(5);
              digitalWrite(7,HIGH);
              delay(5);
              digitalWrite(7,LOW);
              Serial.print("hours");
              Serial.print(": ");
              Serial.println(bcdToDec(hours));
          }
      } 
        if(flag==1){                                              //pretty much the same as hours, so not much to comment
            do{
              PORTB=0xFF;
              delay(5);
              digitalWrite(4,HIGH);
              digitalWrite(5,HIGH);
              digitalWrite(6,HIGH);
              digitalWrite(7,HIGH);
              delay(5);
              digitalWrite(4,LOW);
              digitalWrite(5,LOW);
              digitalWrite(6,LOW);
              digitalWrite(7,LOW);
              flag=0;
              counter=0;
              delay(50);
                while(digitalRead(2)==HIGH){
                  flag=1;
                   Serial.print("minutes");
                   Serial.print(": ");
                   Serial.println(bcdToDec(minutes));
                   PORTB = minutes;
                   delay(5);
                   digitalWrite(4,HIGH);
                   delay(5);
                   digitalWrite(4,LOW);
            
                   PORTB = minutes>>4;
                   delay(5);
                   digitalWrite(5,HIGH);
                   delay(5);
                    digitalWrite(5,LOW);
                    if(digitalRead(3)==LOW){
                     counter = bcdToDec(minutes);
                     counter++;
                     minutes = decToBcd(counter);
                        if((bcdToDec(minutes))==60){
                          minutes=0;
                        }
                      delay(200);
                        PORTB = minutes;
                        delay(5);
                        digitalWrite(4,HIGH);
                        delay(5);
                        digitalWrite(4,LOW);
            
                        PORTB = minutes>>4;
                        delay(5);
                        digitalWrite(5,HIGH);
                        delay(5);
                        digitalWrite(5,LOW);
                        Serial.print("minutes");
                        Serial.print(": ");
                        Serial.println(bcdToDec(minutes));
                    }
                }

                      if(flag==1){                                //send the new values to the DS3231, year day of month and the rest of the registers are not set every time because I don't think that it's necessary.
                        do
                         {
                            Wire.beginTransmission(0x68);
                            Wire.write(0);
                            Wire.write(decToBcd(0));
                            Wire.write(minutes);
                            Wire.write(hours);
                            Wire.endTransmission();
                            Wire.beginTransmission(0x68);
                            Wire.write(4);
                            Wire.write(1);
                            Wire.write(1);
                            Wire.write(18);
                            Wire.endTransmission();
                            flag=0;
                            counter=0;
                                                            
                            } while(digitalRead(2)==LOW);
                            }
                  
            } while(digitalRead(2)==LOW);
          }
        
    } while(digitalRead(2)==LOW);
  }
  delay(1000);
}
  

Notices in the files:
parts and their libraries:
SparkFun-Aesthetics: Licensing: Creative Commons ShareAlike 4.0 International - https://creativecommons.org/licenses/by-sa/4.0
